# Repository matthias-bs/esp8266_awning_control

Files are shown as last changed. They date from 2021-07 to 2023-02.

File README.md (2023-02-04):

# esp8266_awning_control





## ESP8266 (secure) MQTT to ISM Radio Band Awning Remote Control

(using Arduino IDE)

### System Setup
- The awning is normally controlled via a handheld 433 MHz (or other [ISM radio band](https://en.wikipedia.org/wiki/ISM_radio_band) depending on where you live) remote control
- The ESP8266 NodeMCU with [**awning_control**](src/awning_control.ino) sketch provides secure MQTT access via WiFi and converts MQTT messages into radio control sequences sent by the FS1000A RF Transmitter
- An MQTT client, such as a smart phone or tablet with [IoT MQTT Panel](https://snrlab.in/iot/iot-mqtt-panel-user-guide) app, can communicate with awning_control from a remote location
- An MQTT broker (such as a [Raspberry Pi](https://www.raspberrypi.org/) with [Mosquitto](https://mosquitto.org/)) passes control and status messages between the two clients
- **Your awning specific radio remote control sequences must initially be received and recorded as described in [thexperiments /
esp8266_RFControl](https://github.com/thexperiments/esp8266_RFControl)!!!**
- **The transmit algorithm suports only fixed (i.e. non-rolling) codes! This means the remote control must always send the same sequence per command.**
- **Please note: There is no feedback from the awning to _awning_control_!**

see figure below

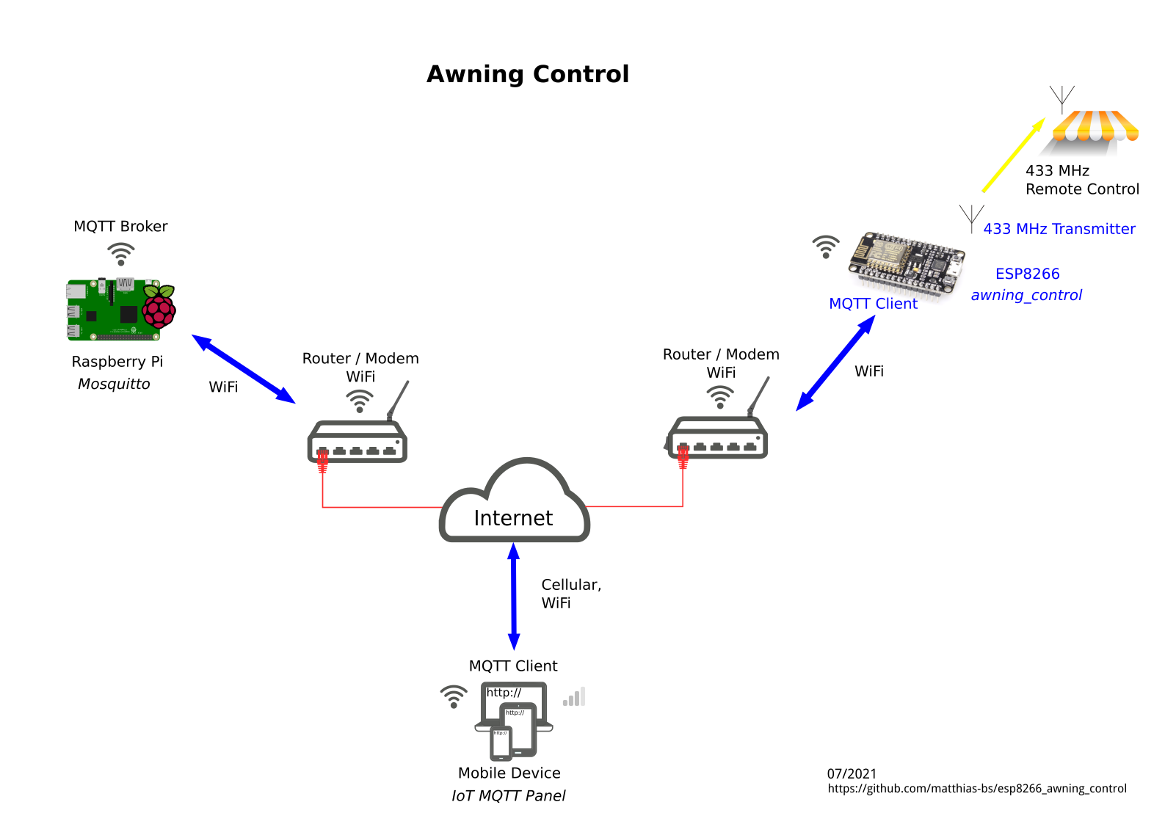
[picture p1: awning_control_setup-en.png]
Awning Control Setup


Copyright Notice:

* https://www.123rf.com/photo_52895758_stock-vector-sign-yellow-awning.html 

   Copyright: [maudis60](https://www.123rf.com/profile_maudis60)

* https://commons.wikimedia.org/wiki/File:Nodemcu_amica_bot_02.png

   Copyright: [Make Magazin DE](https://commons.wikimedia.org/wiki/User:MakeMagazinDE) 

* all other images: 

   creative commons/public domain

### Hardware

**Schematic**

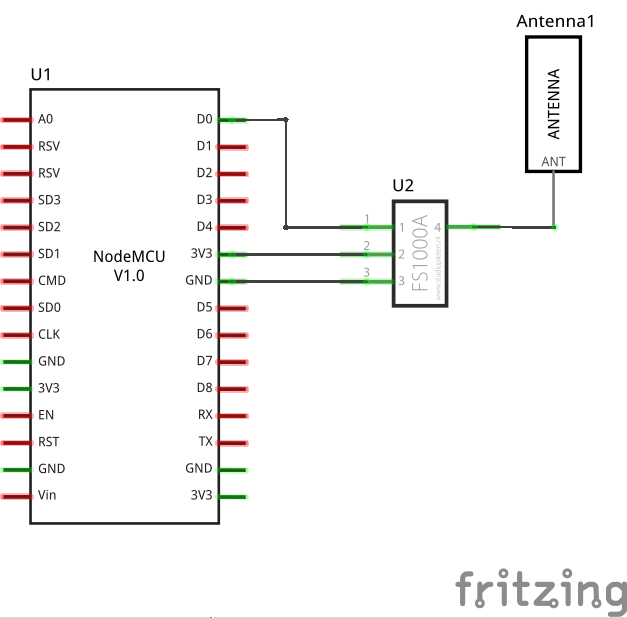
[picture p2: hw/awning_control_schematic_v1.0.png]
Schematic


**ESP8266 NodeMCU, Breadboard, RF Transmitter Module and Antenna**

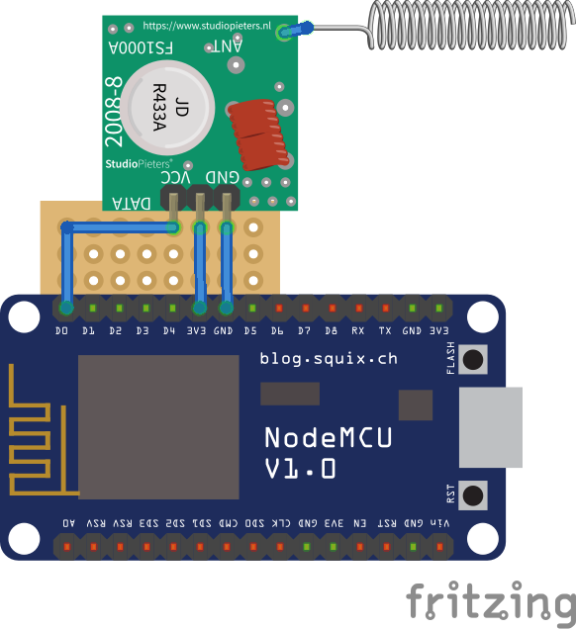
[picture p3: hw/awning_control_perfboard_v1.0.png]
Perfboard


**Fritzing Parts**

<table>
<tr><td>NodeMCU-v1.0              <td>https://github.com/squix78/esp8266-fritzing-parts/blob/master/nodemcu-v1.0/NodeMCUV1.0.fzpz
<tr><td>FS1000A 433MHz Transmitter<td>https://github.com/AchimPieters/Fritzing-Custom-Parts/releases/tag/0.0.1
<tr><td>Antenna                   <td>https://forum.fritzing.org/t/hc-12-module-433mhz-long-range-1-8km/1976
</table>

**Power Supply**

The circuit is powered from the ESP8266 DevKit Micro-USB socket (~70mA @5V).

*__Note:__* Transmitter FS1000a: 3...12V / Receiver YK-MK-5V:   5V

**Bill of Materials**

<table>
<tr>
    <th> Pos.
    <th> Part / Source
    <th> Description
</tr>
<tr>
    <td> 1
    <td> DEBO JT ESP8266 - NodeMCU ESP8266 WiFi-Modul<br>
    https://www.reichelt.de/nodemcu-esp8266-wifi-modul-debo-jt-esp8266-p219900.html<br>
    - or -<br>
    ESP8266 D1 mini
    <td> ESP8266 module
</tr>
<tr>
    <td> 2
    <td> DEBO 433 RX/TX - Entwicklerboards - 433 MHz RX/TX Modul<br>
         https://www.reichelt.de/entwicklerboards-433-mhz-rx-tx-modul-debo-433-rx-tx-p224219.html<br>
         - or -<br>
         kwmobile 3X 433 MHz Sender Empfänger Funk Modul für Arduino und Raspberry Pi -<br>
         Wireless Transmitter Module<br>
         https://smile.amazon.de/gp/product/B01H2D2RH6<br>
         (3 pcs per unit)
    <td> 433 MHz Receiver / Transmitter Modules<br>
         Receiver: YK-MK-5V<br>
         Transmitter: FS1000A
</tr>
<tr>
    <td> 3
    <td> 433MHz Antenne Helical-Antenne Fernbedienung für Arduino Raspberry Pi<br>
        https://smile.amazon.de/gp/product/B00SO651VU<br>
        (10 pcs per unit)
    <td> Antenna<br>
        (a piece of wire might work as well)
</tr>
<tr>
    <td> 4
    <td> Piece of Breadboard
</tr>
<tr>
    <td> 5
    <td> 3x1 Socket Header (2 pcs)
    <td>
</tr>
<tr>
    <td> 6
    <td> Micro-USB to USB-A Cable
    <td>
</tr>
<tr>
    <td> 7
    <td> Case
    <td>
</tr>
<tr>
    <td> 8
    <td> USB Power Supply
    <td>
</tr>
</table>

### Software Variants

* [esp8266_awning_control.ino](https://github.com/matthias-bs/esp8266_awning_control/blob/main/esp8266_awning_control.ino) - WiFi credentials hard coded
* [esp8266_awning_control_wm.ino](https://github.com/matthias-bs/esp8266_awning_control/blob/main/esp8266_awning_control_wm/esp8266_awning_control_wm.ino) - WiFi configuration with [WiFiManager](https://github.com/tzapu/WiFiManager)
   
   **Usage:**
   1. For initial configuration or if connecting with saved credetials failed: Connect a web client to ESP WiFi Access Point defined in `HOSTNAME`
   2. The WiFi Access Point's password is defined in `AP_PASS`
   3. Open http://192.168.4.1 in your web browser and enter your WiFi Access Point credentials.
   
   The information above is also printed to the serial console. The configuration page will time out after 180s and trigger a restart.
   
### Software Configuration
   
**RF Control Sequence**

1. Connect the RF Receiver (YK-MK-5V) to the ESP8266 NodeMCU.

    *__Note 1:__* YK-MK-5V needs a 5V power supply!

    *__Note 2:__* The ESP8266 GPIO pins are **not** 5V-compatible! **Make sure the input voltage from the receiver is limited to 3.3V!** 
   
2. Record your remote control sequences as described in [thexperiments / esp8266_RFControl](https://github.com/thexperiments/esp8266_RFControl).

3. Modify the variables `buckets`, `timings_up`, `timings_stop` and `timings_down` in [awning_control.ino](src/awning_control.ino) accordingly.
   
   `buckets[8]` is an array of pulse and pause lengths in microseconds occurring in a sequence. A pulse is simply the transmission on the ISM radio band carrier frequency (e.g. 433 MHz).
   
   `timings_<up|stop|down>[]` contains indices into `buckets[]`, i.e. it points to the pulse/pause lengths in an alternating fashion.
   
   Example:
   ```
   unsigned long buckets[8] = {344,720,1536,4748,7734,0,0,0};
   char timings_up[] = "3210...";
   ```
   This means:
   1. send a pulse of length #3 (4748µs)
   2. make a pause of length #2 (1536µs)
   3. send a pulse of length #1 (720µs)
   4. make a pause of length #0 (344µs)
   
   etc.
   
4. If one command is working and others are not...
   
   Try to compare the sequences. The `buckets` values should be more or less identical. Are the `timings` different in length? Do you see some striking similarities in the sequences? In my case, the receive algorithm missed the first pulse of the `STOP` sequence. Shifting the array by one position revealed the mainly identical sequences; after adding the first pulse length from the `up` or `down` sequences, the `STOP` command worked fine. 
   
**WiFi, MQTT and Security**

Set up your configuration in a file [secrets.h](https://github.com/matthias-bs/esp8266_awning_control/blob/main/secrets.h) which will be included in [esp8266_awning_control.ino](https://github.com/matthias-bs/esp8266_awning_control/blob/main/esp8266_awning_control.ino) (preferred) or edit the file `awning_control.ino` directly (not recommended). Please refer to [BearSSL_Validation](https://github.com/esp8266/Arduino/tree/master/libraries/ESP8266WiFi/examples/BearSSL_Validation) and [ESP_MQTT_Secure](https://github.com/debsahu/ESP_MQTT_Secure) for details.
   
**Arduino IDE Config**

Arduino IDE Config

### Dashboard with [IoT MQTT Panel](https://snrlab.in/iot/iot-mqtt-panel-user-guide)
awning_control_panel-de+en

**Install _IoT MQTT Panel_ on your Android device**
  
  see [IoT MQTT Panel](https://snrlab.in/iot/iot-mqtt-panel-user-guide)

**Set up *IoT MQTT Panel* from configuration file**

You can either edit the provided [JSON configuration file](IoTMQTTPanel_Awning_Control.json) before importing it or import it as-is and make the required changes in *IoT MQTT Panel*. Don't forget to add the broker's certificate if using Secure MQTT! (in the App: *Connections -> Edit Connections: Certificate path*.)

**Editing [IoTMQTTPanel_Awning_Control.json](IoTMQTTPanel_Awning_Control.json)**

At the beginning, replace the dummy IP address *123.345.678* and port *8883* by your MQTT broker's IP address/hostname and port, change *Your_Client_ID* and *Your_MQTT_Connection* as needed:
```
[...]
"connections":[{"autoConnect":true,"host":"123.345.678","port":8883,"clientId":"Your_Client_ID","connectionName":"Your_MQTT_Connection"
[...]
```

At the end, change *Your_Username* and *Your_Password* as needed:
```
[...]
"username":"Your_Username","password":"Your_Password"
[...]
```

**MQTT Interface**
```
MQTT subscriptions:
     <base_topic>/in           (-)
     <base_topic>/out          ([seconds])
     <base_topic>/stop         (-)

MQTT publications:
     <base_topic>/status       ("online"|"dead"$)
     <base_topic>/last_cmd     ('>' | ']' | '}' | ')' | '<' | '[')*

$ via LWT

*) Last Command Tokens
    > - moving out
    ] - moved  out
    } - moving partially out
    ) - moved  partially out
    < - moving in
    [ - moved  out
```
                                                            
### References and Acknowledgements

1. ESP_MQTT_Secure

    https://github.com/debsahu/ESP_MQTT_Secure

2. esp8266_RFControl
         
    https://github.com/thexperiments/esp8266_RFControl
         
3. RFControl
         
   https://github.com/pimatic/RFControl
        
4. "Raspberry Pi LAN" by Dirk Koudstaal 
   
   https://commons.wikimedia.org/wiki/File:Raspberry_Pi_LAN.svg
         
## Disclaimer and Legal

> This project is a community project not for commercial use.
> The authors will not be held responsible in the event of device failure or damages/injuries due to moving objects without any visual feedback.
> Please think twice about any possible harmful consequences!

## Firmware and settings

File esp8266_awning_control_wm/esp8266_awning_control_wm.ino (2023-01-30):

///////////////////////////////////////////////////////////////////////////////
// awning_control_wm.ino
//
// Awning Control with 433 MHz RF Transmitter via secure MQTT
// for ESP8266 - variant using WiFiManager
//
// - Secure Connection to MQTT Broker via WiFi
// - RF Control commands In/Out/Stop
// - Partial extension of awning by sending stop after defined time
//
// MQTT subscriptions:
//     <base_topic>/in                (-)
//     <base_topic>/out               ([seconds])
//     <base_topic>/stop              (-)
//
// MQTT publications:
//     <base_topic>/status            ("online"|"dead"$)
//     <base_topic>/last_cmd          ('>' | ']' | '}' | ')' | '<' | '[')*
//
// $ via LWT
//
// *)
// > - moving out
// ] - moved  out
// } - moving partially out
// ) - moved  partially out
// < - moving in
// [ - moved  out
//
// created: 06/2021
//
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
// History:
//
// 20210628 Created
// 20210629 Fixed handling of <stop> command while previous command is still
//          executed
//          Fixed RF Control sequence for <stop> command 
// 20230129 Added WiFiManager, improved robustness
//
// ToDo:
// 
//
// Notes:
//
// -
//
///////////////////////////////////////////////////////////////////////////////

#include <ESP8266WiFi.h>      // .arduino15/packages/esp8266/hardware/esp8266/3.1.x/libraries/ESP8266WiFi
#include <WiFiClientSecure.h> // .arduino15/packages/esp8266/hardware/esp8266/3.1.x/libraries/ESP8266WiFi
#include <WiFiManager.h>      // https://github.com/tzapu/WiFiManager
#include <MQTT.h>             // https://github.com/256dpi/arduino-mqtt
#include <RFControl.h>        // https://github.com/pimatic/RFControl
#include <time.h>

const char sketch_id[] = "awning_control_ 20230129";

//enable only one of these below, disabling both is fine too.
// #define CHECK_CA_ROOT
// #define CHECK_PUB_KEY
// #define CHECK_FINGERPRINT
#define CERT cert_ISRG_Root_X1

////--------------------------////

#include "secrets.h"
#ifndef SECRETS
    #define HOSTNAME "awning_control"
    const char *AP_PASS  = "your-ap-passwd";

    const char MQTT_HOST[] = "xxx.yyy.zzz.com";
    const int MQTT_PORT = 8883;
    const char MQTT_USER[] = ""; // leave blank if no credentials used
    const char MQTT_PASS[] = ""; // leave blank if no credentials used

    // see https://github.com/esp8266/Arduino/tree/master/libraries/ESP8266WiFi/examples/BearSSL_Validation
    // cert.py -s <your_broker>:<port> -n SSL
    #ifdef CHECK_CA_ROOT
    static const char digicert[] PROGMEM = R"EOF(
    -----BEGIN CERTIFICATE-----
    xxxxxxxxxxxxxxxxxxxxxxxxxxxxxxxxxxxxxxxxxxxxxxxxxxxxxxxxxxxxxxxx
    xxxxxxxxxxxxxxxxxxxxxxxxxxxxxxxxxxxxxxxxxxxxxxxxxxxxxxxxxxxxxxxx
    xxxxxxxxxxxxxxxxxxxxxxxxxxxxxxxxxxxxxxxxxxxxxxxxxxxxxxxxxxxxxxxx
    xxxxxxxxxxxxxxxxxxxxxxxxxxxxxxxxxxxxxxxxxxxxxxxxxxxxxxxxxxxxxxxx
    xxxxxxxxxxxxxxxxxxxxxxxxxxxxxxxxxxxxxxxxxxxxxxxxxxxxxxxxxxxxxxxx
    xxxxxxxxxxxxxxxxxxxxxxxxxxxxxxxxxxxxxxxxxxxxxxxxxxxxxxxxxxxxxxxx
    xxxxxxxxxxxxxxxxxxxxxxxxxxxxxxxxxxxxxxxxxxxxxxxxxxxxxxxxxxxxxxxx
    xxxxxxxxxxxxxxxxxxxxxxxxxxxxxxxxxxxxxxxxxxxxxxxxxxxxxxxxxxxxxxxx
    xxxxxxxxxxxxxxxxxxxxxxxxxxxxxxxxxxxxxxxxxxxxxxxxxxxxxxxxxxxxxxxx
    xxxxxxxxxxxxxxxxxxxxxxxxxxxxxxxxxxxxxxxxxxxxxxxxxxxxxxxxxxxxxxxx
    xxxxxxxxxxxxxxxxxxxxxxxxxxxxxxxxxxxxxxxxxxxxxxxxxxxxxxxxxxxxxxxx
    xxxxxxxxxxxxxxxxxxxxxxxxxxxxxxxxxxxxxxxxxxxxxxxxxxxxxxxxxxxxxxxx
    xxxxxxxxxxxxxxxxxxxxxxxxxxxxxxxxxxxxxxxxxxxxxxxxxxxxxxxxxxxxxxxx
    xxxxxxxxxxxxxxxxxxxxxxxxxxxxxxxxxxxxxxxxxxxxxxxxxxxxxxxxxxxxxxxx
    xxxxxxxxxxxxxxxxxxxxxxxxxxxxxxxxxxxxxxxxxxxxxxxxxxxxxxxxxxxxxxxx
    xxxxxxxxxxxxxxxxxxxxxxxxxxxxxxxxxxxxxxxxxxxxxxxxxxxxxxxxxxxxxxxx
    xxxxxxxxxxxxxxxxxxxxxxxxxxxxxxxxxxxxxxxxxxxxxxxxxxxxxxxxxxxxxxxx
    xxxxxxxxxxxxxxxxxxxxxxxxxxxxxxxxxxxxxxxxxxxxxxxxxxxxxxxxxxxxxxxx
    xxxxxxxxxxxxxxxxxxxxxxxxxxxxxxxxxxxxxxxxxxxxxxxxxxxxxxxxxxxxxxxx
    xxxxxxxxxxxxxxxxxxxxxxxxxxxxxxxxxxxxxxxxxxxxxxxxxxxxxxxxxxxxxxxx
    xxxxxxxxxxxxxxxxxxxxxxxxxxxxxxxxxxxxxxxxxxxxxxxxxxxxxxxxxxxxxxxx
    xxxxxxxxxxxxxxxxxxxxxxxxxxxxxxxxxxxxxxxxxxxxxxxxxxxxxxxxxxxxxxxx
    xxxxxxxxxxxxxxxxxxxxxxxxxxxxxxxxxxxxxxxxxxxxxxxxxxxxxxxxxxxxxxxx
    xxxxxxxxxxxxxxxxxxxxxxxxxxxxxxxxxxxxxxxxxxxxxxxxxxxxxxxxxxxxxxxx
    xxxxxxxxxxxxxxxxxxxxxxxxxxxxxxxxxxxxxxxxxxxxxxxxxxxxxxxxxxxxxxxx
    xxxxxxxxxxxxxxxxxxxxxxxxxxxxxxxxxxxxxxxxxxxxxxxxxxxxxxxxxxxxxxxx
    xxxxxxxxxxxxxxxxxxxxxxxxxxxxxxxxxxxxxxxx
    -----END CERTIFICATE-----
    )EOF";
    #endif

    #ifdef CHECK_PUB_KEY
    // Extracted by: openssl x509 -pubkey -noout -in ca.crt
    static const char pubkey[] PROGMEM = R"KEY(
    -----BEGIN PUBLIC KEY-----
    xxxxxxxxxxxxxxxxxxxxxxxxxxxxxxxxxxxxxxxxxxxxxxxxxxxxxxxxxxxxxxxx
    xxxxxxxxxxxxxxxxxxxxxxxxxxxxxxxxxxxxxxxxxxxxxxxxxxxxxxxxxxxxxxxx
    xxxxxxxxxxxxxxxxxxxxxxxxxxxxxxxxxxxxxxxxxxxxxxxxxxxxxxxxxxxxxxxx
    xxxxxxxxxxxxxxxxxxxxxxxxxxxxxxxxxxxxxxxxxxxxxxxxxxxxxxxxxxxxxxxx
    xxxxxxxxxxxxxxxxxxxxxxxxxxxxxxxxxxxxxxxxxxxxxxxxxxxxxxxxxxxxxxxx
    xxxxxxxxxxxxxxxxxxxxxxxxxxxxxxxxxxxxxxxxxxxxxxxxxxxxxxxxxxxxxxxx
    xxxxxxxxxxxxxxxxxxxxxxxxxxxxxxxxxxxxxxxxxxxxxxxxxxxxxxxxxxxxxxxx
    xxxxxxxxxxxxxxxxxxxxxxxxxxxxxxxxxxxxxxxxxxxxxxxxxxxxxxxxxxxxxxxx
    xxxxxxxx
    -----END PUBLIC KEY-----
    )KEY";
    #endif

    #ifdef CHECK_FINGERPRINT
	// Extracted by: openssl x509 -fingerprint -in fullchain.pem
    static const char fp[] PROGMEM = "AA:BB:CC:DD:EE:FF:00:11:22:33:44:55:66:77:88:99:AA:BB:CC:DD";
    #endif
#endif
    
const int SEND_PIN        = 16; // GPIO16 - D0 on nodeMCU
const int REPEATS         = 3;  // no. of RF remote control command repetitions
const int CONN_RETRIES    = 10; // no. of retries for failing WiFi/MQTT connection 
const unsigned int t_busy = 40000; // time required to move awning completely in/out

// RF remote control pulse sequences
unsigned long buckets[8] = {344,720,1536,4748,7734,0,0,0};

// buckets=340,724,1536,4756,7732,0,0,0&timings=32100101101010010101010110011001010101011001100110011001010101011001010110010101103210010110101001010101011001100101010101100110011001100101010101100101011001010114&repeats=3
char timings_in[] = "3210010110101001010101011001100101010101100110011001100101010101100101011001010114";

char timings_stop[] = "3210010110101001010101011001100101010101100110011001100101010101100110011001100114";

// buckets=340,724,1556,4740,7736,0,0,0&timings=32100101101010010101010110011001010101011001100110011001010101011001011010010110103210010110101001010101011001100101010101100110011001100101010101100101101001011014&repeats=3
char timings_out[] = "3210010110101001010101011001100101010101100110011001100101010101100101101001011014";

// MQTT topics
const char MQTT_SUB_IN[]     = HOSTNAME "/in";
const char MQTT_SUB_OUT[]    = HOSTNAME "/out";
const char MQTT_SUB_STOP[]   = HOSTNAME "/stop";
const char MQTT_PUB_STATUS[] = HOSTNAME "/status";
const char MQTT_PUB_CMD[]    = HOSTNAME "/last_cmd";


//////////////////////////////////////////////////////

#if (defined(CHECK_PUB_KEY) and defined(CHECK_CA_ROOT)) or (defined(CHECK_PUB_KEY) and defined(CHECK_FINGERPRINT)) or (defined(CHECK_FINGERPRINT) and defined(CHECK_CA_ROOT)) or (defined(CHECK_PUB_KEY) and defined(CHECK_CA_ROOT) and defined(CHECK_FINGERPRINT))
#error "cant have both CHECK_CA_ROOT and CHECK_PUB_KEY enabled"
#endif

BearSSL::WiFiClientSecure net;
MQTTClient client;

unsigned long lastMillis = 0;
time_t now;
char last_cmd[2] = "-";
unsigned long ts_stop = 0;
bool new_cmd = false;

void mqtt_connect()
{
    Serial.print("Checking WiFi...");
    int count = 0;
    while (WiFi.status() != WL_CONNECTED)
    {
        Serial.print(".");
        delay(1000);
        if (++count == CONN_RETRIES) {
            Serial.println("wifi connection failed.");
            ESP.restart();
        }
    }

    Serial.print("\nMQTT connecting ");
    count = 0;
    while (!client.connect(HOSTNAME, MQTT_USER, MQTT_PASS))
    {
        Serial.print(".");
        delay(1000);
        if (++count == CONN_RETRIES) {
            Serial.println("MQTT connection failed.");
            ESP.restart();
        }
        
    }

    Serial.println("connected!");
    client.subscribe(MQTT_SUB_IN);
    client.subscribe(MQTT_SUB_OUT);
    client.subscribe(MQTT_SUB_STOP);

}

void messageReceived(String &topic, String &payload)
{
    Serial.println("Received [" + topic + "]: " + payload);

    if (last_cmd[0] == '>' || last_cmd[0] == '<' || last_cmd[0] == '}') {
        if (topic != MQTT_SUB_STOP) {
            Serial.println("Busy - command ignored!");
            return;
        }
    }
    new_cmd = true;
    if (topic == MQTT_SUB_IN) {
        Serial.println("CMD: in");
        RFControl::sendByCompressedTimings(SEND_PIN, buckets, timings_in, REPEATS);
        last_cmd[0] = '<';
        ts_stop = millis() + t_busy;
    } else if (topic == MQTT_SUB_OUT) {
        int t = 0;
        if (payload != "") {
            t = payload.toInt();
        }
        Serial.println("CMD: out");
        RFControl::sendByCompressedTimings(SEND_PIN, buckets, timings_out, REPEATS);
        
        if (t > 0) {
            Serial.println(String(t));
            last_cmd[0] = '}';
            ts_stop = millis() + t * 1000;
        } else {
            last_cmd[0] = '>';
            ts_stop = millis() + t_busy;
        }
    } else if (topic == MQTT_SUB_STOP) {
        Serial.println("CMD: stop");
        RFControl::sendByCompressedTimings(SEND_PIN, buckets, timings_stop, REPEATS);
        last_cmd[0] = '#';
        ts_stop = millis();
    }
}

void setup()
{
    Serial.begin(115200);
    //Serial.setDebugOutput(true);
    Serial.println();
    Serial.println();
    Serial.println(sketch_id);
    Serial.println();
    Serial.print("Connect a web client to ESP Access Point: ");
    Serial.println(HOSTNAME);
    Serial.print("Password: ");
    Serial.println(AP_PASS);
    Serial.println("Open http://192.168.4.1 in your web browser and enter your WiFi Access Point credentials.");
    
    WiFiManager wm;

    // After a timeout, the autoConnect function will return regardless of the result
    wm.setConfigPortalTimeout(180);
    
    bool res;
    // res = wm.autoConnect(); // auto generated AP name from chipid
    // res = wm.autoConnect("AutoConnectAP"); // anonymous ap
    res = wm.autoConnect(HOSTNAME, AP_PASS); // password protected ap
    
    if (!res) {
        Serial.println("Failed to connect");
        ESP.restart();
    } 
    
    Serial.println("connected!");

    Serial.print("Setting time using SNTP ");
    configTime(-5 * 3600, 0, "pool.ntp.org", "time.nist.gov");
    now = time(nullptr);
    int count = 0;
    while (now < 1510592825)
    {
        delay(500);
        Serial.print(".");
        now = time(nullptr);
        if (count == CONN_RETRIES) {
            Serial.println("Failed to set time.");
            ESP.restart();
        }
    }
    Serial.println("done!");
    struct tm timeinfo;
    gmtime_r(&now, &timeinfo);
    Serial.print("Current time: ");
    Serial.print(asctime(&timeinfo));
  
    #ifdef CHECK_CA_ROOT
        //BearSSL::X509List cert(digicert);
        BearSSL::X509List cert(CERT);
        net.setTrustAnchors(&cert);
    #endif
    #ifdef CHECK_PUB_KEY
        BearSSL::PublicKey key(pubkey);
        net.setKnownKey(&key);
    #endif
    #ifdef CHECK_FINGERPRINT
        net.setFingerprint(fp);
    #endif
    #if (!defined(CHECK_PUB_KEY) and !defined(CHECK_CA_ROOT) and !defined(CHECK_FINGERPRINT))
        net.setInsecure();
    #endif

    client.begin(MQTT_HOST, MQTT_PORT, net);
    client.onMessage(messageReceived);
    client.setWill(MQTT_PUB_STATUS, "dead", true /* retained*/, true /* qos */);
    mqtt_connect();
}

void loop()
{
    if (WiFi.status() != WL_CONNECTED)
    {
        Serial.print("Checking wifi" );
        while (WiFi.waitForConnectResult() != WL_CONNECTED)
        {
            //WiFi.begin(ssid, pass);
            Serial.print(".");
            delay(10);
        }
        Serial.println("connected");
    }
    else
    {
        if (!client.connected())
        {
            mqtt_connect();
        }
        else
        {
            client.loop();
        }
    }

    if ((last_cmd[0] == '}') && (millis() > ts_stop)) {  
        Serial.println("stop");
        RFControl::sendByCompressedTimings(SEND_PIN, buckets, timings_stop, REPEATS);
        last_cmd[0] = ')';
    }
    if ((last_cmd[0] == '>') && (millis() > ts_stop)) {  
        Serial.println("out");
        last_cmd[0] = ']';
    }
    if ((last_cmd[0] == '<') && (millis() > ts_stop)) {  
        Serial.println("in");
        last_cmd[0] = '[';
    }    

    // publish a message roughly every second.
    if ((millis() - lastMillis > 5000) || new_cmd)
    {
        new_cmd = false;
        lastMillis = millis();
        client.publish(MQTT_PUB_CMD, last_cmd, false, 0);
        client.publish(MQTT_PUB_STATUS, "online", false, 0);
    }
}

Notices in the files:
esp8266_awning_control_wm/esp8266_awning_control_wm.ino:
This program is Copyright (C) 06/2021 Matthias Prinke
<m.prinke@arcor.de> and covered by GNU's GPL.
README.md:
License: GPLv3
